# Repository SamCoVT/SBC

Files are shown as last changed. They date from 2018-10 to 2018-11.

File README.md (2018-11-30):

# SBC
SamCo's Single Board Computer (65C02)

This single board computer was constructed for fun.  It has the
following specifications:

* 65C02 processor
* 32K RAM (with 256 addresses reserved for I/O)
* 32K ROM 
* 65C22 Versatile Interface Adapter (VIA)
* 65C51 Asynchronous Communications Interface Adapter (ACIA)
* 2x16 LCD
* Support for USB or external 5V power

After trying out writing programs in assembly and in BASIC, I found
the [Tali Forth 2](https://github.com/scotws/TaliForth2) project, and
that's what I've been using as an operating system/programming
language ever since.

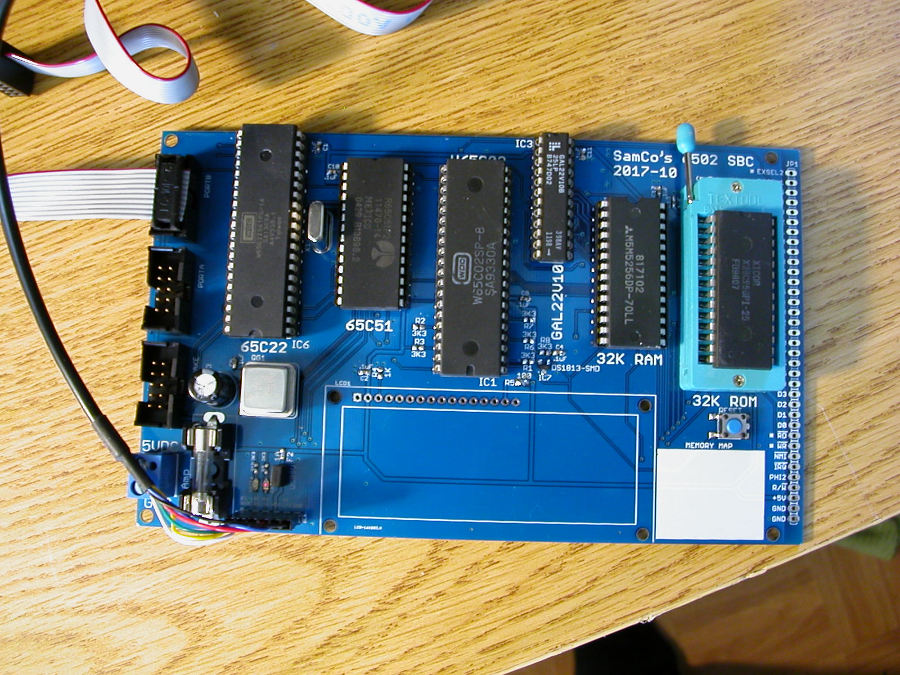
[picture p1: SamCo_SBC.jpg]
A 65C02-based Single Board Computer


## Memory Map

The memory map is currently as follows:

|Memory Range | Function|
|---|---|
|$0000-$7EFF  | RAM|
|$7F00-$7F3F  | VIA (65C22 - parallel I/O)|
|$7F40-$7F7F  | EXSEL1 (External Select #1) (Active Low)|
|$7F80-$7FBF  | ACIA (65C51 - Serial port)|
|$7FC0-$7FFF  | LCD|

The EXSEL1 line is brought out to the expansion bus on the righ
side of the PCB and is available for use.  The EXSEL2 line is an
active-high version of the /RESET signal.  Both of these signals are
not currently used by the SBC and can be repurposed by reprogramming
the GAL.

The memory decoding is handled by a GAL22V10, programmed from the
ADDECODE.PLD file.  I used Wincupl (run under Wine on Linux) to
generate the .jed (JEDEC) file, and then I used Galblast on an old
Windows 98 machine with a parallel port adapter to program the GAL.

## Errata

* Because I used a WDC65C22S (which has a totem-pole IRQ output rather
  than the WDC65C22N which has an open drain IRQ output,) I had to cut
  the IRQ trace and add a Schottky diode (cathode towards pin 21 of
  IC6) across the gap.

* I needed to add approximately 30pF of capacitance to the ACIA
  crystal to get it to start up and oscillate reliably.  No provision
  was made on the board for this, so I added it on the back side of
  the board between pins 1 and 6.  I also needed to add a 1Meg Ohm
  resistor across the crystal pins when using an RCA CDP65C51 (but did
  not need this when using a Rockwell part.)

# License
The Eagle schematic board files are provided here under a Creative
Commons BY-SA 2.0 (CC BY-SA 2.0) license.

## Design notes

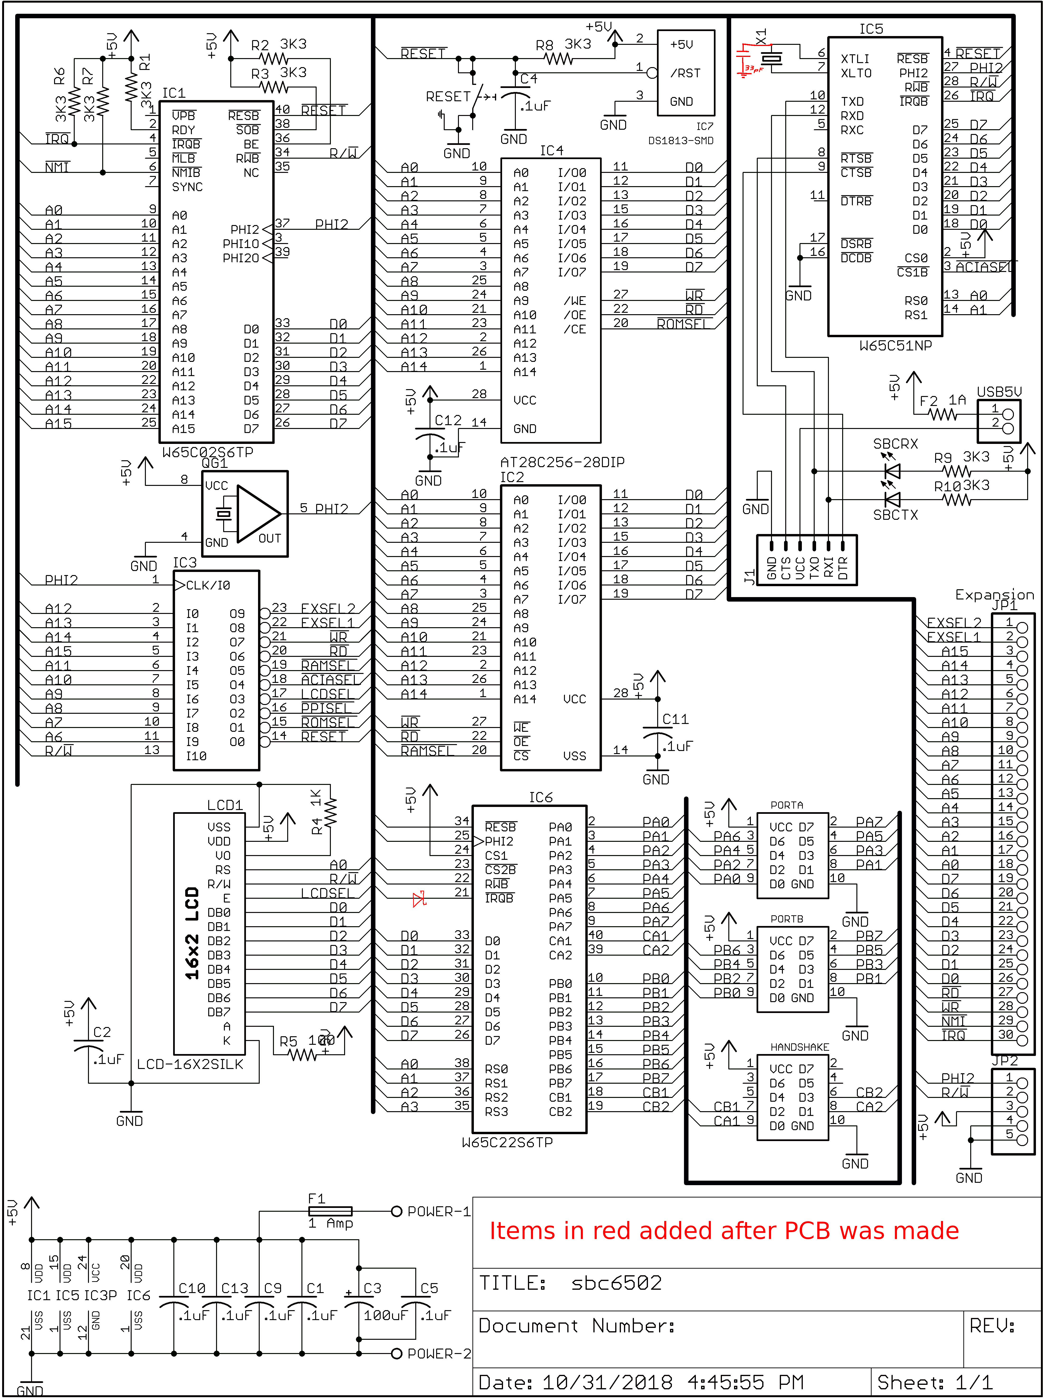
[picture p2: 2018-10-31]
sbc6502.png

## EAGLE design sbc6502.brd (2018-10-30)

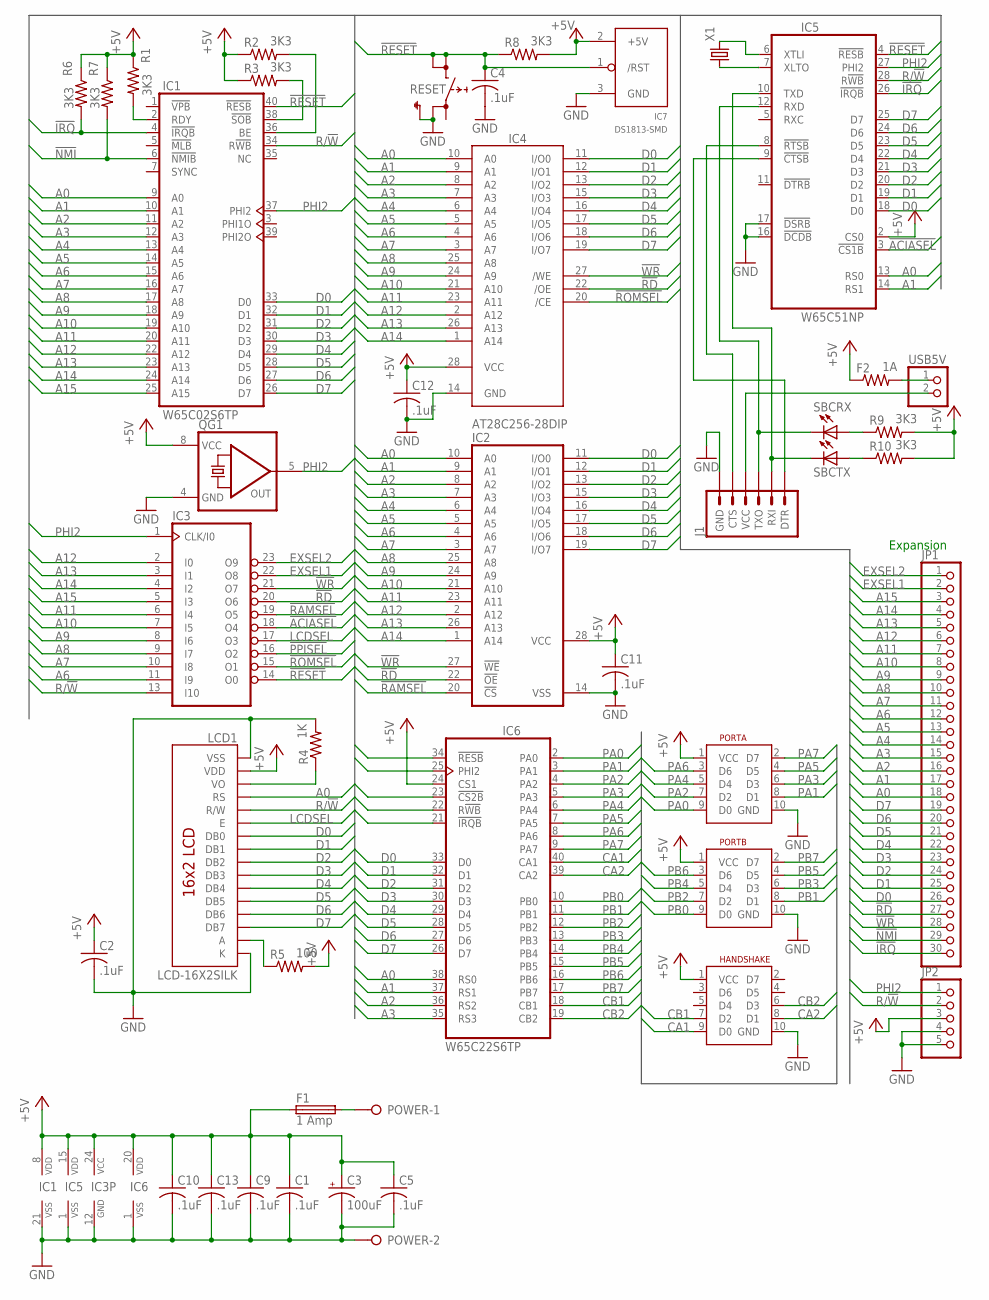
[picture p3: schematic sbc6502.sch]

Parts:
C1, C2, C4, C5, C9, C10, C11, C12, C13: .1uF; C0603K
C3: 100uF; E5-8,5
F1: 1 Amp; SH25
F2: 1A; R0603
HANDSHAKE: 8BIT_HEADER_SHROUDED; 2X05_SHROUDED
IC1: W65C02S6TP; DIL40
IC2: 62256P; DIL28-6
IC3: 22V10; DIL24-3
IC4: AT28C256-28DIP; DIL28-6
IC5: W65C51NP; DIL28-6
IC6: W65C22S6TP; DIL40
IC7: DS1813-SMD; SOT-23
J1: 6_PIN_SERIAL_TARGET; 1X06
JP1: PINHD-1X30; 1X30
JP2: PINHD-1X5; 1X05
LCD1: LCD-16X2SILK; LCD-16X2
PORTA: 8BIT_HEADER_SHROUDED; 2X05_SHROUDED
PORTB: 8BIT_HEADER_SHROUDED; 2X05_SHROUDED
POWER: W237-02P; W237-132
QG1: QG5460; DIL08S
R1, R2, R3, R6, R7, R8, R9, R10: 3K3; R0603
R4: 1K; R0603
R5: 100; R0805
RESET: SKHMPSE010; SKHMPXE010
SBCRX: LEDCHIPLED_0805; CHIPLED_0805
SBCTX: LEDCHIPLED_0805; CHIPLED_0805
USB5V: PINHD-1X2; 1X02
X1: CRYSTALHC49U-V; HC49U-V

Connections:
!ACIASEL: IC3.18 (O4), IC5.3 (!CS1B)
!IRQ: IC1.4 (!IRQB), IC5.26 (!IRQB), IC6.21 (!IRQB), JP1.30, R6.2
!NMI: IC1.6 (!NMIB), JP1.29, R7.2
!PPISEL: IC3.16 (O2), IC6.23 (!CS2B)
!RAMSEL: IC2.20 (!CS), IC3.19 (O5)
!RD: IC2.22 (!OE), IC3.20 (O6), IC4.22 (/OE), JP1.27
!RESET: C4.1, IC1.40 (!RESB), IC3.14 (O0), IC5.4 (!RESB), IC6.34 (!RESB), IC7.1 (/RST), R8.1, RESET.3 (2.1), RESET.4 (2.2)
!ROMSEL: IC3.15 (O1), IC4.20 (/CE)
!WR: IC2.27 (!WE), IC3.21 (O7), IC4.27 (/WE), JP1.28
+5V: C1.1, C2.1, C3.+, C5.1, C9.1, C10.1, C11.1, C12.1, C13.1, F1.1, F2.1, HANDSHAKE.1 (VCC), IC1.8 (VDD), IC2.28 (VCC), IC3.24 (VCC), IC4.28 (VCC), IC5.2 (CS0), IC5.15 (VDD), IC6.20 (VDD), IC6.24 (CS1), IC7.2 (+5V), JP2.3, LCD1.2 (VDD), PORTA.1 (VCC), PORTB.1 (VCC), QG1.8 (VCC), R1.1, R2.1, R3.1, R5.2, R6.1, R7.1, R8.2, R9.2, R10.2
A0: IC1.9 (A0), IC2.10 (A0), IC4.10 (A0), IC5.13 (RS0), IC6.38 (RS0), JP1.18, LCD1.4 (RS)
A1: IC1.10 (A1), IC2.9 (A1), IC4.9 (A1), IC5.14 (RS1), IC6.37 (RS1), JP1.17
A2: IC1.11 (A2), IC2.8 (A2), IC4.8 (A2), IC6.36 (RS2), JP1.16
A3: IC1.12 (A3), IC2.7 (A3), IC4.7 (A3), IC6.35 (RS3), JP1.15
A4: IC1.13 (A4), IC2.6 (A4), IC4.6 (A4), JP1.14
A5: IC1.14 (A5), IC2.5 (A5), IC4.5 (A5), JP1.13
A6: IC1.15 (A6), IC2.4 (A6), IC3.11 (I9), IC4.4 (A6), JP1.12
A7: IC1.16 (A7), IC2.3 (A7), IC3.10 (I8), IC4.3 (A7), JP1.11
A8: IC1.17 (A8), IC2.25 (A8), IC3.9 (I7), IC4.25 (A8), JP1.10
A9: IC1.18 (A9), IC2.24 (A9), IC3.8 (I6), IC4.24 (A9), JP1.9
A10: IC1.19 (A10), IC2.21 (A10), IC3.7 (I5), IC4.21 (A10), JP1.8
A11: IC1.20 (A11), IC2.23 (A11), IC3.6 (I4), IC4.23 (A11), JP1.7
A12: IC1.22 (A12), IC2.2 (A12), IC3.2 (I0), IC4.2 (A12), JP1.6
A13: IC1.23 (A13), IC2.26 (A13), IC3.3 (I1), IC4.26 (A13), JP1.5
A14: IC1.24 (A14), IC2.1 (A14), IC3.4 (I2), IC4.1 (A14), JP1.4
A15: IC1.25 (A15), IC3.5 (I3), JP1.3
CA1: HANDSHAKE.9 (D0), IC6.40 (CA1)
CA2: HANDSHAKE.8 (D1), IC6.39 (CA2)
CB1: HANDSHAKE.7 (D2), IC6.18 (CB1)
CB2: HANDSHAKE.6 (D3), IC6.19 (CB2)
D0: IC1.33 (D0), IC2.11 (I/O0), IC4.11 (I/O0), IC5.18 (D0), IC6.33 (D0), JP1.26, LCD1.7 (DB0)
D1: IC1.32 (D1), IC2.12 (I/O1), IC4.12 (I/O1), IC5.19 (D1), IC6.32 (D1), JP1.25, LCD1.8 (DB1)
D2: IC1.31 (D2), IC2.13 (I/O2), IC4.13 (I/O2), IC5.20 (D2), IC6.31 (D2), JP1.24, LCD1.9 (DB2)
D3: IC1.30 (D3), IC2.15 (I/O3), IC4.15 (I/O3), IC5.21 (D3), IC6.30 (D3), JP1.23, LCD1.10 (DB3)
D4: IC1.29 (D4), IC2.16 (I/O4), IC4.16 (I/O4), IC5.22 (D4), IC6.29 (D4), JP1.22, LCD1.11 (DB4)
D5: IC1.28 (D5), IC2.17 (I/O5), IC4.17 (I/O5), IC5.23 (D5), IC6.28 (D5), JP1.21, LCD1.12 (DB5)
D6: IC1.27 (D6), IC2.18 (I/O6), IC4.18 (I/O6), IC5.24 (D6), IC6.27 (D6), JP1.20, LCD1.13 (DB6)
D7: IC1.26 (D7), IC2.19 (I/O7), IC4.19 (I/O7), IC5.25 (D7), IC6.26 (D7), JP1.19, LCD1.14 (DB7)
EXSEL1: IC3.22 (O8), JP1.2
EXSEL2: IC3.23 (O9), JP1.1
GND: C1.2, C2.2, C3.-, C4.2, C5.2, C9.2, C10.2, C11.2, C12.2, C13.2, HANDSHAKE.10 (GND), IC1.21 (VSS), IC2.14 (VSS), IC3.12 (GND), IC4.14 (GND), IC5.1 (VSS), IC5.16 (!DCDB), IC5.17 (!DSRB), IC6.1 (VSS), IC7.3 (GND), J1.6 (GND), JP2.4, JP2.5, LCD1.1 (VSS), LCD1.16 (K), PORTA.10 (GND), PORTB.10 (GND), POWER.2, QG1.4 (GND), R4.2, RESET.2 (1.2), RESET.5 (SH)
LCDSEL: IC3.17 (O3), LCD1.6 (E)
unnamed: LCD1.15 (A), R5.1
unnamed: LCD1.3 (VO), R4.1
unnamed: R9.1, SBCRX.A
unnamed: R10.1, SBCTX.A
unnamed: IC1.2 (RDY), R1.2
unnamed: IC1.38 (!SOB), R3.2
unnamed: IC1.36 (BE), R2.2
unnamed: IC5.7 (XLTO), X1.1
unnamed: IC5.6 (XTLI), X1.2
unnamed: J1.4 (VCC), USB5V.2
unnamed: F1.2, POWER.1
unnamed: F2.2, USB5V.1
PA0: IC6.2 (PA0), PORTA.9 (D0)
PA1: IC6.3 (PA1), PORTA.8 (D1)
PA2: IC6.4 (PA2), PORTA.7 (D2)
PA3: IC6.5 (PA3), PORTA.6 (D3)
PA4: IC6.6 (PA4), PORTA.5 (D4)
PA5: IC6.7 (PA5), PORTA.4 (D5)
PA6: IC6.8 (PA6), PORTA.3 (D6)
PA7: IC6.9 (PA7), PORTA.2 (D7)
PB0: IC6.10 (PB0), PORTB.9 (D0)
PB1: IC6.11 (PB1), PORTB.8 (D1)
PB2: IC6.12 (PB2), PORTB.7 (D2)
PB3: IC6.13 (PB3), PORTB.6 (D3)
PB4: IC6.14 (PB4), PORTB.5 (D4)
PB5: IC6.15 (PB5), PORTB.4 (D5)
PB6: IC6.16 (PB6), PORTB.3 (D6)
PB7: IC6.17 (PB7), PORTB.2 (D7)
PHI2: IC1.37 (PHI2), IC3.1 (CLK/I0), IC5.27 (PHI2), IC6.25 (PHI2), JP2.1, QG1.5 (OUT)
R/!W!: IC1.34 (R!WB), IC3.13 (I10), IC5.28 (R!WB), IC6.22 (R!WB), JP2.2, LCD1.5 (R/W)
SBCRX: IC5.12 (RXD), J1.3 (TXO), SBCRX.C
SBC_CTS: IC5.9 (!CTSB), J1.1 (DTR)
SBC_RTS: IC5.8 (!RTSB), J1.5 (CTS)
SBC_TX: IC5.10 (TXD), J1.2 (RXI), SBCTX.C

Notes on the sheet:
Expansion

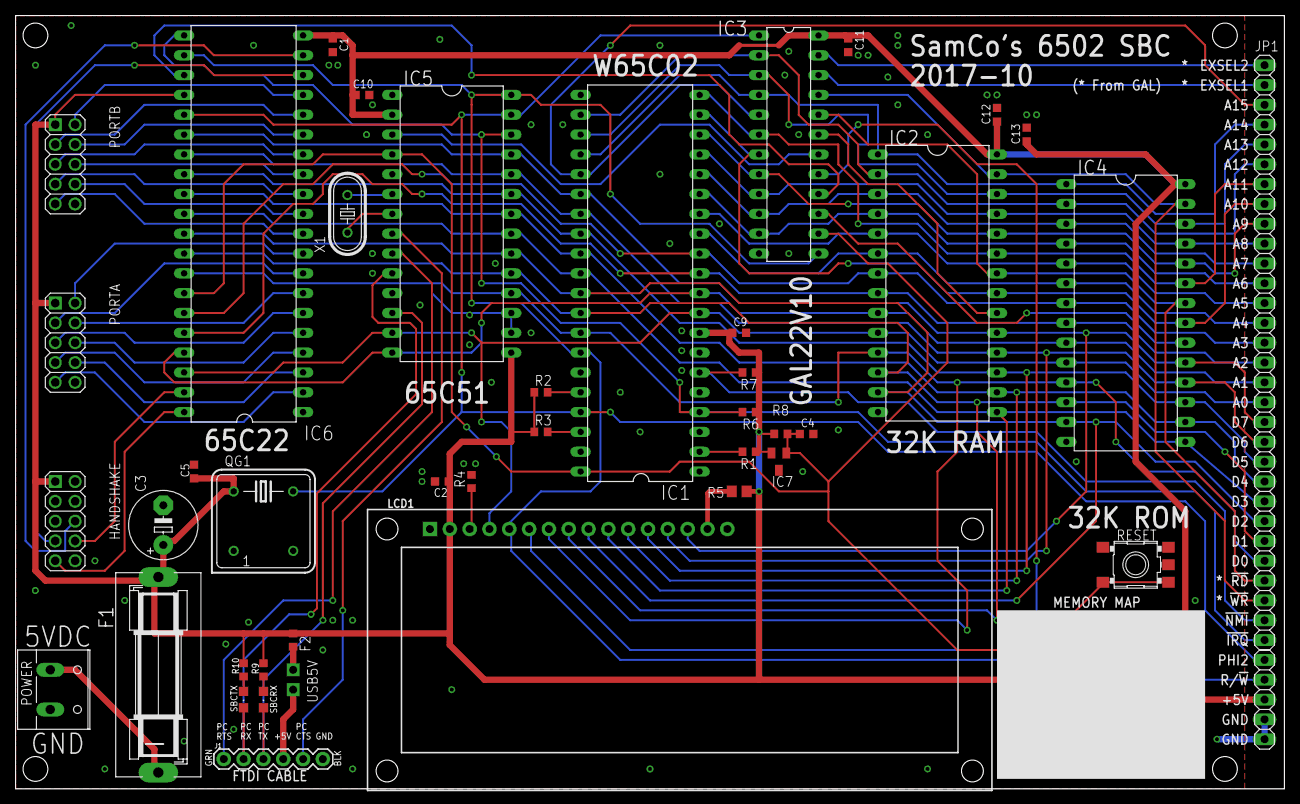
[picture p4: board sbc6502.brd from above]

Board: 2 copper layers, 162.6 x 99.1 mm, 43 parts (0 on the bottom side), 76 nets.

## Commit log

2018-10-30 Initial files for SBC
    [sbc6502.brd, sbc6502.sch]
2018-10-31 Adding schematic as a PNG image
2018-11-18 I2C routines for Tali Forth 2
    These should be added to the user words to handle a 24FC1025 128K EEPROM on PORTA of the VIA.
    SDA (Serial DAta) is on PORTA Bit 7
    SCL (Serial CLock) is on PORTA Bit 0
2018-11-18 Address Decoder GAL files
    I'm using a GAL22V10, programmed with GALBLAST via the parallel port on an old Win98 machine.
    The PIT (Programmable Interval Timer) mentioned in the ADDECODE.PLD file was never used, and that output (connected to EXSEL1 on the PCB) is available as an active low select line for the addresses $7F40-7F7F. The EXSEL2 on the PCB is currently configured as an active high reset. Both of these can be reconfigured, if desired, as they are not currently used by any of the current hardware.
2018-11-18 Update i2c.fs
    Switch back to decimal at the end.
2018-11-29 Update i2c.fs
    Remove comment mentioning the need to load blocks.fs first, as Tali2 already has these words now.
2018-12-09 Update i2c for vectored block I/O
    When assemblerizing the block words, the `BLOCK-READ` and `BLOCK-WRITE` words changed from deferred words (which don't work in ROM) to vectored words using `BLOCK-READ-VECTOR` and `BLOCK-WRITE-VECTOR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

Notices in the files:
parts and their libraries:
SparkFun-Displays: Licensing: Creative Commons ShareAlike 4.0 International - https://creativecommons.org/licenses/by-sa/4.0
